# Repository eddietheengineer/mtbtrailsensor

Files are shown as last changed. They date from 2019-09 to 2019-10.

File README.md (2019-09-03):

# Mountain Bike Trail Sensor

Goal: Standalone IoT device to monitor real trail conditions

Most mountain bike trails today have some sort of "trail status" webpage--most of them are updated by trail stewards who regularly ride the trails and update them depending on the conditions. Generally there are four potential statuses

  Red: Wet/muddy, riding will damage the trail surface
  Yellow: Mostly dry except a few isolated spots, ride with caution
  Green: Good to go!
  Blue: Trail is frozen (good)
  
This system works okay when the trail is frequently ridden, but on more remote/less used trails it becomes problematic because the trail sometimes may not get an update for weeks. This project is to develop a sensor that will take regular measurements of the environment and automatically update trail conditions via the internet. 

Bill of Materials:
  
      $69 - Particle Electron (cellular IoT device)
      $0  - Lipo Battery (2000mAh) - included with Electron
      $10 - FreedomPop SIM Card (200MB/month free data)
      $3  - BME280 Sensor (Air Temp/Humidity/Pressure)
      $2  - DS18B20 Sensor (Waterproof Temperature Sensor -- Ground Temperature)
      $2  - TMP36 Sensor (Air Temp inside Enclosure for development--if it gets too hot)
      $1  - Capacitive Soil Moisture Sensor V1.2 (Soil Moisture)
      $1  - NPN Transistor (Switch power to sensors off during sleep)
      $5  - 2.5W 5V/500mA Solar Panel
      Total: $93
     
Current readings (still tweaking code):
  https://thingspeak.com/channels/852007

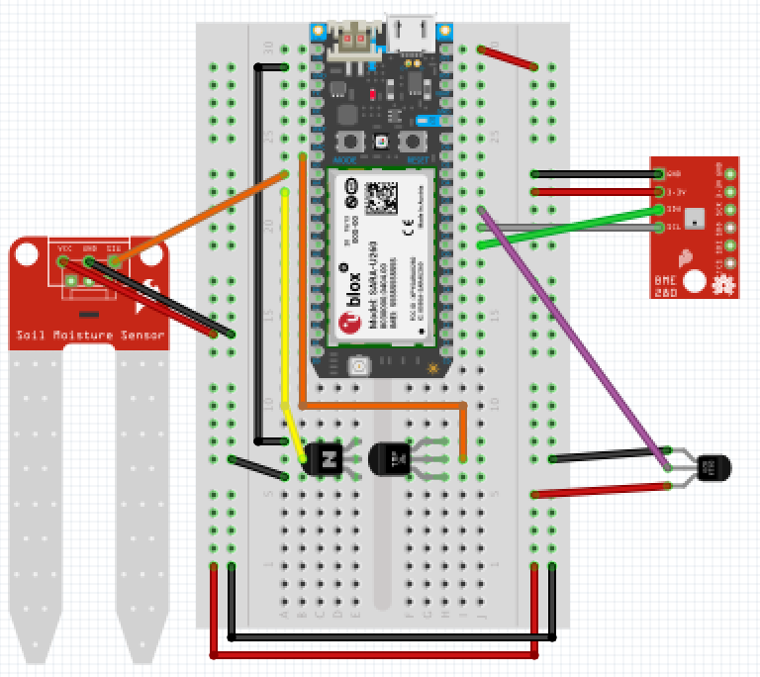
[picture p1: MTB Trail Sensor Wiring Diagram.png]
Image of Wiring


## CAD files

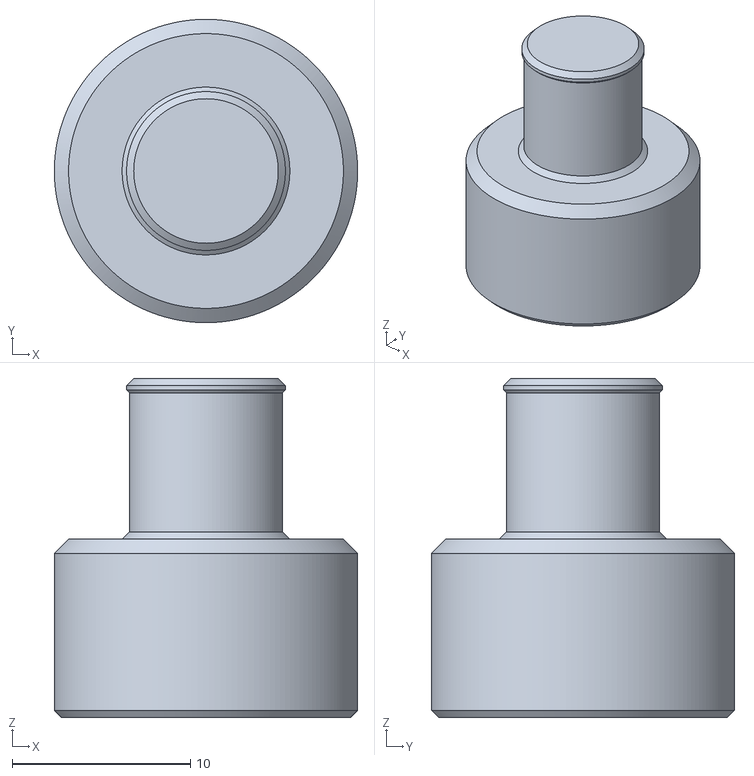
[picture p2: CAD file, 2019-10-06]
STL Files/Peg.stl
17.0 x 17.0 x 19.0

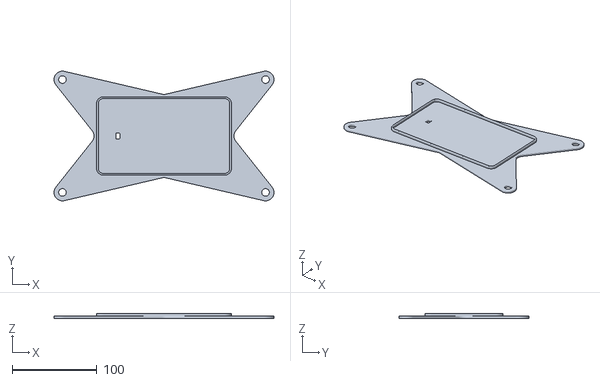
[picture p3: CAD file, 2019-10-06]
STL Files/Lid.stl
260.0 x 153.3 x 6.00

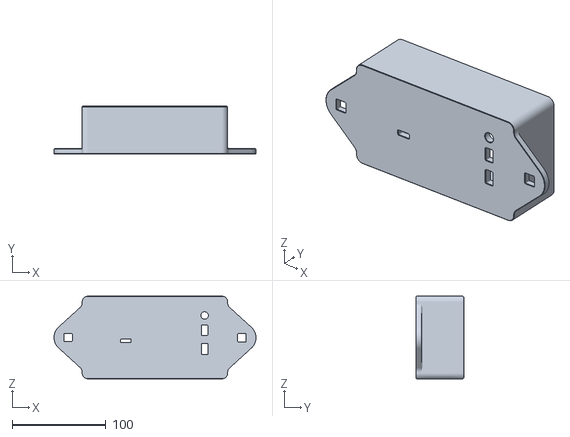
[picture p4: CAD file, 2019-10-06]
STL Files/Base.stl
215.2 x 51.0 x 88.0

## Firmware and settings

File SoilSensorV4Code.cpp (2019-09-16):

//BME280 configuration
#include <SparkFunBME280.h>
BME280 airSensor;

//Thingspeak client configuration
#include <ThingSpeak.h>
TCPClient client;
unsigned int myChannelNumber = YOURCHANNELID; // replace with your ChannelID
const char * myWriteAPIKey = "YOURAPIKEY"; // replace with your WriteAPIKey

//FreedomPop Configuration -- if you use Particle SIM, you do not need this
STARTUP(cellular_credentials_set("fp.com.attz", "", "", NULL));

//This allows us to wait to connect to cellular until we want to
SYSTEM_MODE(SEMI_AUTOMATIC);

//Configure DS18B20 waterproof temp sensor
#include <DS18B20.h>
#include <math.h>
const int      MAXRETRY          = 4;
DS18B20  ds18b20(D2, true); //Sets Pin D2 for Water Temp Sensor and 
char     szInfo[64];

#define TMP36Sig A5 //Pin that TMP36 analog output is connected to
#define PowerPin A3 //Pin that drives NPN transistor to power sensors
#define soilSenseCapPin A4 //Pin that Capacitance sensor is connected to

PMIC pmic; //Charge Controller
FuelGauge fuel; //Battery Monitor


float soilSenseCap;
float airTemp;
float airPressure;
float airHumidity;
float airDewpoint;
float groundTemp;
float enclosureTemp;
float voltage;
float fuelLevel;
float chargeStatus;

void setup() {
    //Turn off RGB Led to conserve power
    RGB.control(true);
    RGB.color(0,0,0);
    
    //Initialize Serial Communication
    Serial.begin(57600);

    //switch NPN transistor to power sensors
    pinMode(PowerPin, OUTPUT);
    digitalWrite(PowerPin, HIGH);

    //Configure Charge Controller for Solar Panel
    //pmic.begin();
    //pmic.setChargeCurrent(0,0,1,0,0,0);
    //pmic.setInputVoltageLimit(4840);
    //chargeStatus = pmic.getSystemStatus();
    
            //Serial.print("Charge Status: ");
            //Serial.println(chargeStatus);

    //Configure BME280
  	airSensor.settings.commInterface = I2C_MODE;
	airSensor.settings.I2CAddress = 0x76; //may be 0x77 depending on your sensor
	airSensor.settings.runMode = 3; //Normal mode
	airSensor.settings.tStandby = 0;
	airSensor.settings.filter = 4;
	airSensor.settings.tempOverSample = 5;
    airSensor.settings.pressOverSample = 5;
	airSensor.settings.humidOverSample = 1;
	delay(10); // BME280 takes <5ms to power up
	airSensor.begin();
  
    //Initialize ThingSpeak client
    ThingSpeak.begin(client);
}

void loop() {

    if(fuel.getSoC() > 20){
        Serial.println("");
        delay(100);
        getAirTemp();
        delay(100);
        getGroundTemp();
        getEnclosureTemp();
        getSoilData();
        getBatteryLevel();
        publishData();
    }
    
    System.sleep(SLEEP_MODE_DEEP, 300);
}

void getAirTemp(){
    float airTempC = airSensor.readTempC();
    airTemp = airSensor.readTempF();
    airPressure = airSensor.readFloatPressure()*29.9212/101325;
    airHumidity = airSensor.readFloatHumidity();
    
    if(airTempC > 0)
    {
        float a = 6.1121;
        float b = 17.368;
        float c = 238.88;
        float Gamma = log(airHumidity/100) + (b*airTempC)/(c + airTempC);
        airDewpoint = (c*Gamma)/(b - Gamma);
    }
    if(airTempC < 0)
    {
        float a = 6.1121;
        float b = 17.966;
        float c = 247.15;
        float Gamma = log(airHumidity/100) + (b*airTempC)/(c + airTempC);
        airDewpoint = (c*Gamma)/(b - Gamma);
    }
    
    
    
	        /*Serial.print("Temperature: ");
	        Serial.print(airTemp, 2);
        	Serial.println(" degrees F");
        	
        	Serial.print("Temperature: ");
	        Serial.print(airSensor.readTempF(), 2);
	        Serial.println(" degrees F");

        	Serial.print("Pressure: ");
        	Serial.print(airPressure, 2);
        	Serial.println(" Pa");

        	Serial.print("%RH: ");
        	Serial.print(airHumidity, 2);
        	Serial.println(" %");*/
}

void getGroundTemp(){
    float _temp;
    float celsius;
    int   i = 0;

    do {
        _temp = ds18b20.getTemperature();
    } while (!ds18b20.crcCheck() && MAXRETRY > i++);

    if (i < MAXRETRY) {
        celsius = _temp;
        groundTemp = ds18b20.convertToFahrenheit(_temp);
            
            Serial.print("Gnd Temp (F): ");
            Serial.println(groundTemp);
    }
    else {
        celsius = groundTemp = NAN;
            
            Serial.println("Invalid reading");
  }
}

void getEnclosureTemp() {
    float enclosureTempC = (analogRead(TMP36Sig)*3300/4096-500);
    float enclosureTempF = enclosureTempC*9/5+320;
    enclosureTemp = enclosureTempF/10;
    
            Serial.print("Enc Temp (F): ");
            Serial.println(enclosureTemp);
}

void getSoilData(){
    soilSenseCap = analogRead(soilSenseCapPin);
    
            Serial.print("Soil Sense: ");
            Serial.println(soilSenseCap);
}

void getBatteryLevel() {
    fuelLevel = fuel.getSoC()*100/80;
    voltage = fuel.getVCell();
    
            Serial.print("Battery (V): ");
            Serial.println(voltage);
            Serial.print("Battery (%): ");
            Serial.println(fuelLevel);
}

void publishData(){
            Serial.println("Publishing now.");
    
    Cellular.on();
    Cellular.connect();
    Particle.connect();
    
        ThingSpeak.setField(1, airTemp);
        ThingSpeak.setField(2, airHumidity);
        ThingSpeak.setField(3, airDewpoint);
        ThingSpeak.setField(4, airPressure);
        ThingSpeak.setField(5, groundTemp);
        ThingSpeak.setField(6, soilSenseCap);
        ThingSpeak.setField(7, enclosureTemp);
        ThingSpeak.setField(8, fuelLevel);
        ThingSpeak.writeFields(myChannelNumber, myWriteAPIKey);
        
    Particle.process();
    delay(5000);
    Particle.disconnect();
    Cellular.off();
}

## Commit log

2019-09-03 Add Wiring Diagram
    [mtbtrailsensor.fzz]
2019-09-03 Update MTB Trail Sensor Wiring Diagram.png
2019-09-16 Add air pressure and dewpoint calculation
    Dewpoint calculation formula from Wikipedia, which references constants from "Journal of Applied Meteorology and Climatology"
2019-10-06 Add CAD files for enclosure
    [Base.stl, Lid.stl, Peg.stl]
